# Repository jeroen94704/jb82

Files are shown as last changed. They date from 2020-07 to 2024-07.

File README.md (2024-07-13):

# JB82: A compact, 82-key mechanical keyboard

I'm a bit of a keyboard nerd, and my life's problem was that I couldn't find a keyboard that perfectly fit my preferences:

* Reasonably compact
* Full row of dedicated F-keys
* A complete set of nav-keys (home/end, ins/del, pgup/pgdn)
* Not have all the keys crammed together, so I can feel my way to the nav-keys

The layout in this repo has all that. Here you will find the kicad project for the PCB design and some supporting files for the 3D-printable case (which can be found here: https://www.printables.com/model/626812-jb82-keyboard-enclosure) and the keyboard firmware.

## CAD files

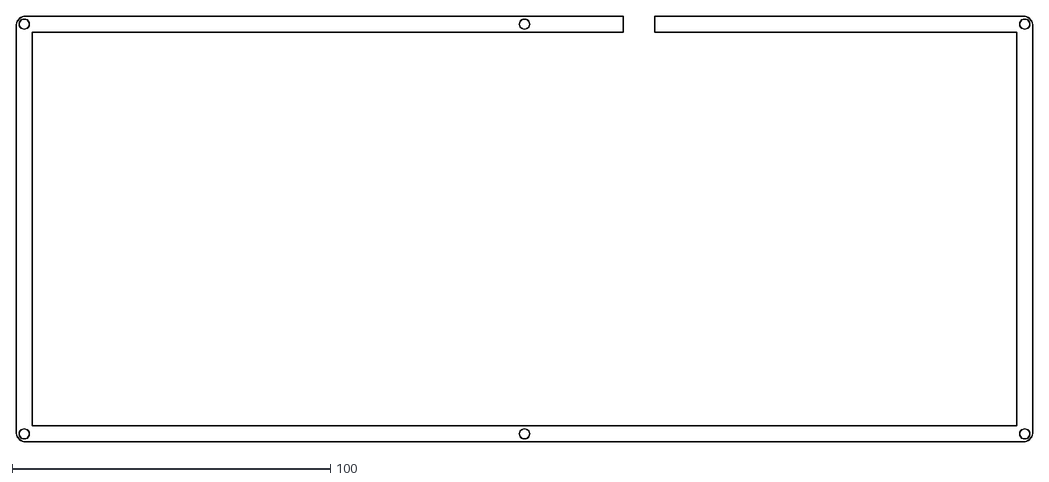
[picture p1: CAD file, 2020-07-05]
CaseBuilder/open_layer.dxf
319.6 x 133.8

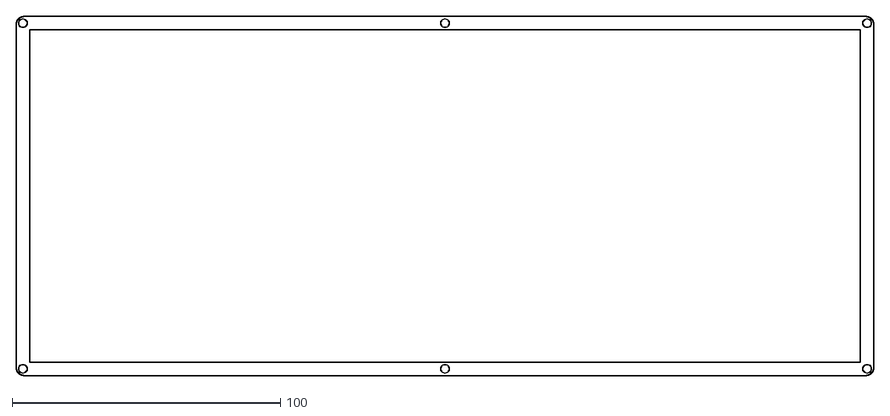
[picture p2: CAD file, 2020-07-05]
CaseBuilder/closed_layer.dxf
319.6 x 133.8

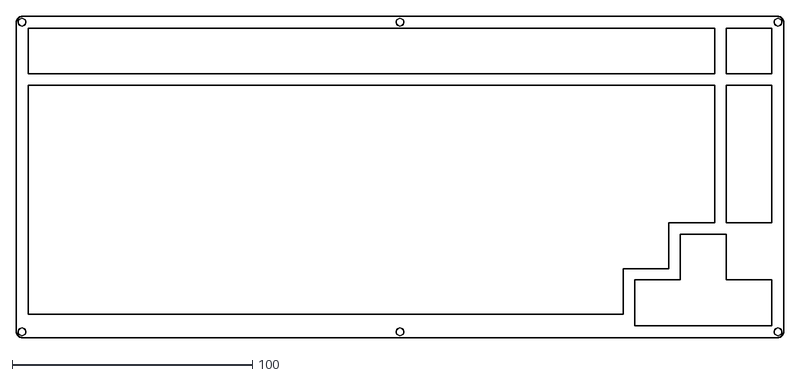
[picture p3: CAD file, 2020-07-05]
CaseBuilder/top_layer.dxf
319.6 x 133.8

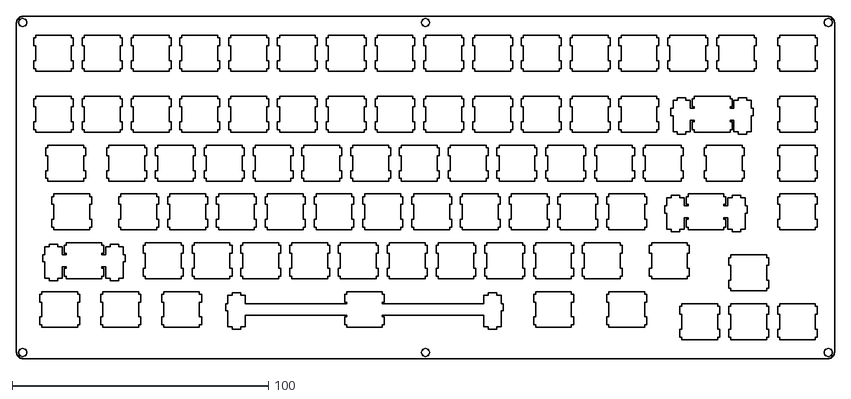
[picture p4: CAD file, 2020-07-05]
CaseBuilder/switch_plate.dxf
319.6 x 133.8

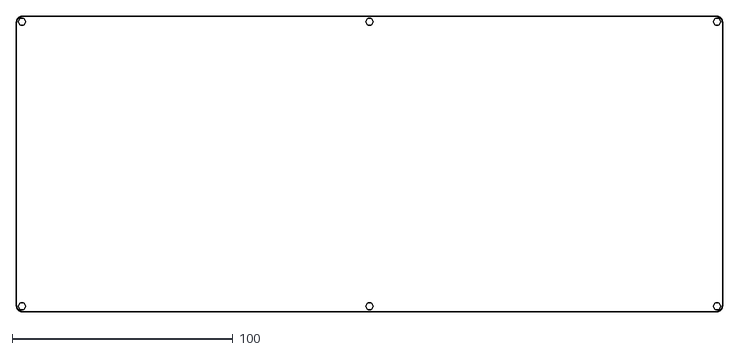
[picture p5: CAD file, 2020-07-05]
CaseBuilder/bottom_plate.dxf
319.6 x 133.8

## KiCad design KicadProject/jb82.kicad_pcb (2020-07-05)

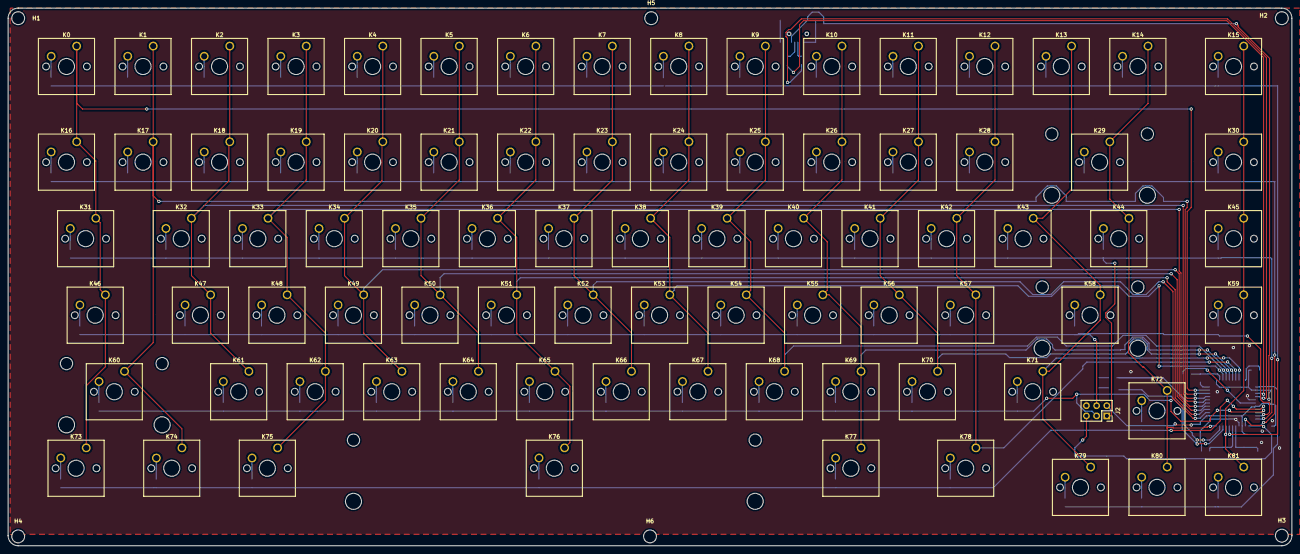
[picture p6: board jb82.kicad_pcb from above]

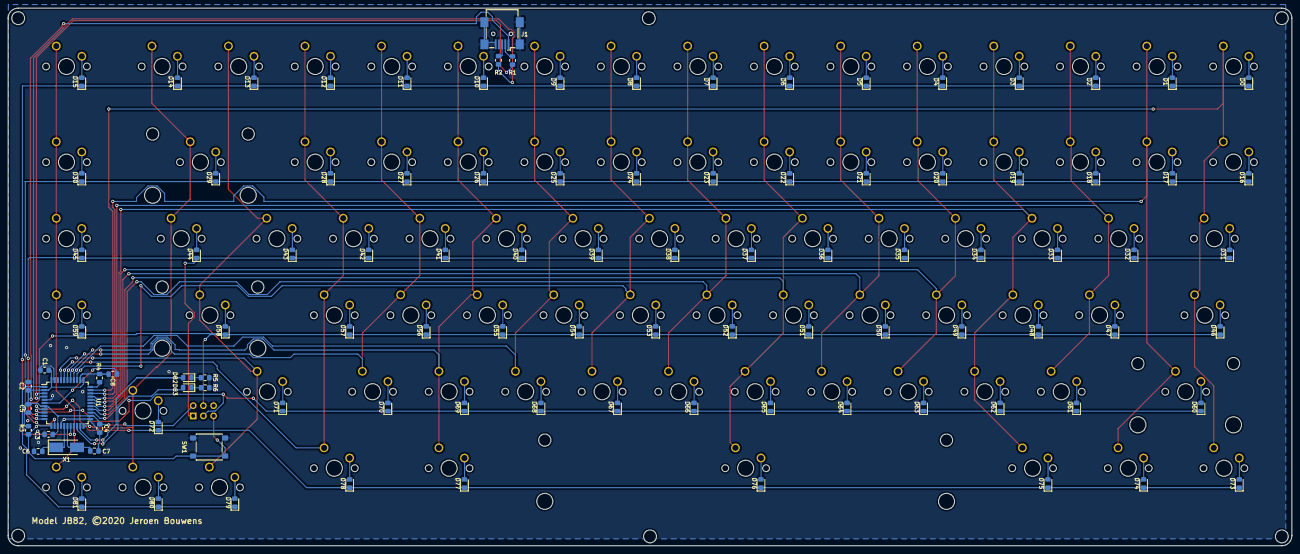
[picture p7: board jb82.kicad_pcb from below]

Board: 2 copper layers, 319.6 x 133.8 mm, 191 parts (102 on the bottom side), 120 nets.

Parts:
C1, C2, C3, C4: 0.1u; C_0805_2012Metric_Pad1.15x1.40mm_HandSolder
C5: 4.7u; C_0805_2012Metric_Pad1.15x1.40mm_HandSolder
C6, C7: 22p; C_0805_2012Metric_Pad1.15x1.40mm_HandSolder
C8: 1u; C_0805_2012Metric_Pad1.15x1.40mm_HandSolder
D0, D1, D2, D3, D4, D5, D6, D7, D8, D9, D10, D11, D12, D13, D14, D15, D16, D17, D18, D19, D20, D21, D22, D23, D24, D25, D26, D27, D28, D29, D30, D31, D32, D33, D34, D35, D36, D37, D38, D39, D40, D41, D42, D43, D44, D45, D46, D47, D48, D49, D50, D51, D52, D53, D54, D55, D56, D57, D58, D59, D60, D61, D62, D63, D64, D65, D66, D67, D68, D69, D70, D71, D72, D73, D74, D75, D76, D77, D78, D79, D80, D81: D; D_0805_2012Metric_Pad1.15x1.40mm_HandSolder
D82, D83: LED; LED_0805_2012Metric_Pad1.15x1.40mm_HandSolder
H1, H2, H3, H4, H5, H6: MountingHole; MountingHole_3.2mm_M3_DIN965
J1: USB_mini_micro_B; USB_Mini-B_Wuerth_65100516121_Horizontal
J2: Conn_02x03_Odd_Even; PinSocket_2x03_P2.54mm_Vertical
K0, K1, K2, K3, K4, K5, K6, K7, K8, K9, K10, K11, K12, K13, K14, K15, K16, K17, K18, K19, K20, K21, K22, K23, K24, K25, K26, K27, K28, K30, K32, K33, K34, K35, K36, K37, K38, K39, K40, K41, K42, K43, K45, K47, K48, K49, K50, K51, K52, K53, K54, K55, K56, K57, K59, K61, K62, K63, K64, K65, K66, K67, K68, K69, K70, K72, K79, K80, K81: KEYSW; SW_Cherry_MX_1.00u_PCB
K29: KEYSW; SW_Cherry_MX_2.00u_PCB
K31, K44, K77, K78: KEYSW; SW_Cherry_MX_1.50u_PCB
K46, K71: KEYSW; SW_Cherry_MX_1.75u_PCB
K58, K60: KEYSW; SW_Cherry_MX_2.25u_PCB
K73, K74, K75: KEYSW; SW_Cherry_MX_1.25u_PCB
K76: KEYSW; SW_Cherry_MX_6.25u_PCB
R1, R2: 22; R_0805_2012Metric_Pad1.15x1.40mm_HandSolder
R3, R4: 10k; R_0805_2012Metric_Pad1.15x1.40mm_HandSolder
R5, R6: 180R; R_0805_2012Metric_Pad1.15x1.40mm_HandSolder
SW1: SW_PUSH; SW_Push_1P1T_NO_6x6mm_H9.5mm
U1: ATMEGA32U4; TQFP-44_10x10mm_P0.8mm
X1: XTAL; Crystal_SMD_5032-2Pin_5.0x3.2mm_HandSoldering

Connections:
/Col_0: K0.1, K16.1, K31.1, K46.1, K73.1, U1.32
/Col_1: K1.1, K17.1, K60.1, K74.1, U1.31
/Col_2: K2.1, K18.1, K32.1, K47.1, K61.1, U1.30
/Col_3: K3.1, K19.1, K33.1, K48.1, K62.1, K75.1, U1.29
/Col_4: K4.1, K20.1, K34.1, K49.1, K63.1, U1.28
/Col_5: K5.1, K21.1, K35.1, K50.1, K64.1, U1.27
/Col_6: K6.1, K22.1, K36.1, K51.1, K65.1, K76.1, U1.26
/Col_7: K7.1, K23.1, K37.1, K52.1, K66.1, U1.25
/Col_8: K8.1, K24.1, K38.1, K53.1, K67.1, U1.36
/Col_9: K9.1, K25.1, K39.1, K54.1, K68.1, U1.37
/Col_10: K10.1, K26.1, K40.1, K55.1, K69.1, K77.1, U1.38
/Col_11: K11.1, K27.1, K41.1, K56.1, K70.1, U1.39
/Col_12: K12.1, K28.1, K42.1, K57.1, K78.1, U1.40
/Col_13: K13.1, K43.1, K58.1, K71.1, K79.1, U1.41
/Col_14: K14.1, K29.1, K44.1, K72.1, K80.1, U1.22
/Col_15: K15.1, K30.1, K45.1, K59.1, K81.1, U1.19
/Misc1: D82.2, U1.21
/Misc2: D83.2, U1.20
/Reset: J2.5, R3.1, SW1.2, U1.13
/Row_0: D0.1, D1.1, D2.1, D3.1, D4.1, D5.1, D6.1, D7.1, D8.1, D9.1, D10.1, D11.1, D12.1, D13.1, D14.1, D15.1, U1.18
/Row_1: D16.1, D17.1, D18.1, D19.1, D20.1, D21.1, D22.1, D23.1, D24.1, D25.1, D26.1, D27.1, D28.1, D29.1, D30.1, U1.12
/Row_2: D31.1, D32.1, D33.1, D34.1, D35.1, D36.1, D37.1, D38.1, D39.1, D40.1, D41.1, D42.1, D43.1, D44.1, D45.1, J2.1, U1.11
/Row_3: D46.1, D47.1, D48.1, D49.1, D50.1, D51.1, D52.1, D53.1, D54.1, D55.1, D56.1, D57.1, D58.1, D59.1, J2.4, U1.10
/Row_4: D60.1, D61.1, D62.1, D63.1, D64.1, D65.1, D66.1, D67.1, D68.1, D69.1, D70.1, D71.1, J2.3, U1.9
/Row_5: D72.1, D73.1, D74.1, D75.1, D76.1, D77.1, D78.1, U1.8
/Row_6: D79.1, D80.1, D81.1, U1.1
GND: C1.2, C2.2, C3.2, C4.2, C5.2, C6.2, C7.2, C8.2, J1.5, J1.6, J2.6, R4.1, R5.2, R6.2, SW1.1, U1.5, U1.15, U1.23, U1.35, U1.43
unnamed: C6.1, U1.16, X1.1
unnamed: C7.1, U1.17, X1.2
unnamed: C8.1, U1.6
unnamed: D0.2, K0.2
unnamed: D1.2, K1.2
unnamed: D2.2, K2.2
unnamed: D3.2, K3.2
unnamed: D4.2, K4.2
unnamed: D5.2, K5.2
unnamed: D6.2, K6.2
unnamed: D7.2, K7.2
unnamed: D8.2, K8.2
unnamed: D9.2, K9.2
unnamed: D10.2, K10.2
unnamed: D11.2, K11.2
unnamed: D12.2, K12.2
unnamed: D13.2, K13.2
unnamed: D14.2, K14.2
unnamed: D15.2, K15.2
unnamed: D16.2, K16.2
unnamed: D17.2, K17.2
unnamed: D18.2, K18.2
unnamed: D19.2, K19.2
unnamed: D20.2, K20.2
unnamed: D21.2, K21.2
unnamed: D22.2, K22.2
unnamed: D23.2, K23.2
unnamed: D24.2, K24.2
unnamed: D25.2, K25.2
unnamed: D26.2, K26.2
unnamed: D27.2, K27.2
unnamed: D28.2, K28.2
unnamed: D29.2, K29.2
unnamed: D30.2, K30.2
unnamed: D31.2, K31.2
unnamed: D32.2, K32.2
unnamed: D33.2, K33.2
unnamed: D34.2, K34.2
unnamed: D35.2, K35.2
unnamed: D36.2, K36.2
unnamed: D37.2, K37.2
unnamed: D38.2, K38.2
unnamed: D39.2, K39.2
unnamed: D40.2, K40.2
unnamed: D41.2, K41.2
unnamed: D42.2, K42.2
unnamed: D43.2, K43.2
unnamed: D44.2, K44.2
unnamed: D45.2, K45.2
unnamed: D46.2, K46.2
unnamed: D47.2, K47.2
unnamed: D48.2, K48.2
unnamed: D49.2, K49.2
unnamed: D50.2, K50.2
unnamed: D51.2, K51.2
unnamed: D52.2, K52.2
unnamed: D53.2, K53.2
unnamed: D54.2, K54.2
unnamed: D55.2, K55.2
unnamed: D56.2, K56.2
unnamed: D57.2, K57.2
unnamed: D58.2, K58.2
unnamed: D59.2, K59.2
unnamed: D60.2, K60.2
unnamed: D61.2, K61.2
unnamed: D62.2, K62.2
unnamed: D63.2, K63.2
unnamed: D64.2, K64.2
unnamed: D65.2, K65.2
unnamed: D66.2, K66.2
unnamed: D67.2, K67.2
unnamed: D68.2, K68.2
unnamed: D69.2, K69.2
unnamed: D70.2, K70.2
unnamed: D71.2, K71.2
unnamed: D72.2, K72.2
unnamed: D73.2, K73.2
unnamed: D74.2, K74.2
unnamed: D75.2, K75.2
unnamed: D76.2, K76.2
unnamed: D77.2, K77.2
unnamed: D78.2, K78.2
unnamed: D79.2, K79.2
unnamed: D80.2, K80.2
unnamed: D81.2, K81.2
unnamed: D82.1, R5.1
unnamed: D83.1, R6.1
unnamed: J1.2, R1.2
unnamed: J1.3, R2.2
unnamed: R1.1, U1.3
unnamed: R2.1, U1.4
unnamed: R4.2, U1.33
VCC: C1.1, C2.1, C3.1, C4.1, C5.1, J1.1, J2.2, R3.2, U1.2, U1.7, U1.14, U1.24, U1.34, U1.44

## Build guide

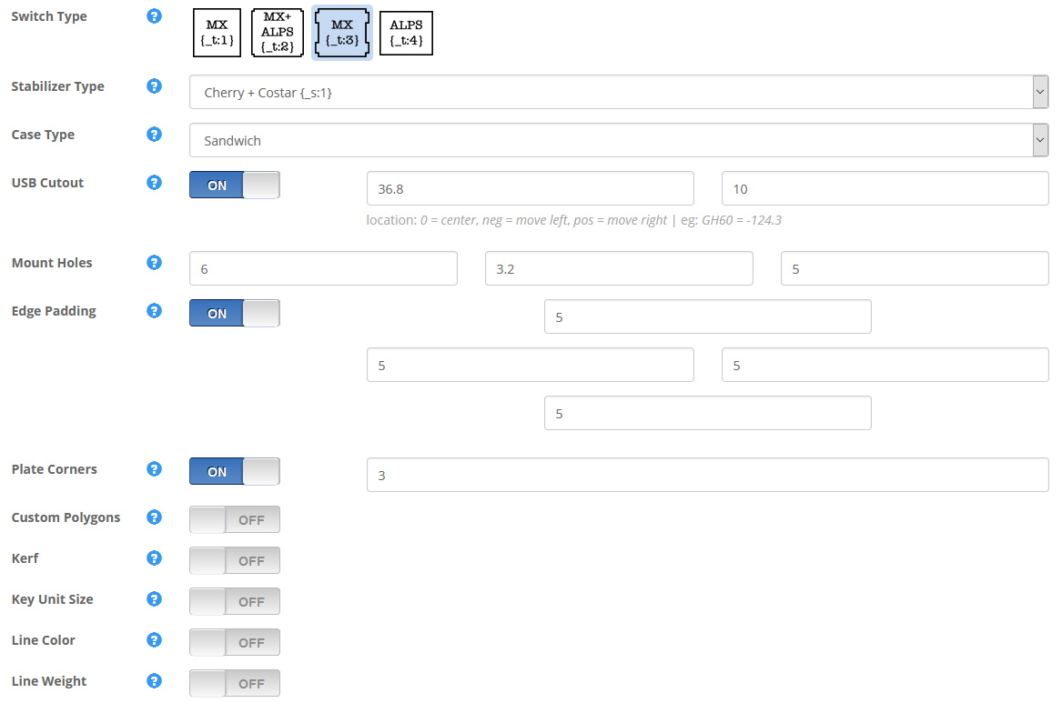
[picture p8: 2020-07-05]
CaseBuilder/casebuilder_settings.jpg

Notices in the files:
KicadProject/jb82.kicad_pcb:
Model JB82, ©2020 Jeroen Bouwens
